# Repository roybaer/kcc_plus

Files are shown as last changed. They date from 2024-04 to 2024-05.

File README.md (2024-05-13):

# KCC plus - a new, enhanced, CPC6128 compatible home computer

**WORK IN PROGRESS**

The _KCC plus_ is a retroactively designed hypothetical early 1990s successor to the KC compact.
The KC compact was a largely compatible clone of the Amstrad CPC 6128, built without custom silicon.

Once completed, it can be considered a cousin of, but not a clone of the Amstrad 6128 Plus.

## Planned feature set

The following hardware features are currently planned

- Between 256 KiB and 1024 KiB of RAM, ideally as a pair of SRAM chips
- Two AY-2-8910 PSGs for additional polyphony and additional control lines, on-board Digiblaster
- 16 bit data path for pixel generation and duplication of the relevant logic for twice the color depth
- Bypassable EGA-like latch in the second RAM chip's data path to keep block fill/copy operations fast
- At least one attribute mode, e.g. for colorful high-res pseudo text modes
- Possibility to optionally double the CPU clock and/or FDC clock, if feasible
- Floppy disk and tape interface
- Internal IDE and Serial ports, if feasible
- The CPC 6128's form factor: System board should fit inside a German CPC 6128 case
- High quality keyboard with n-key rollover
- 50-pin micro ribbon expansion port
- Bi-directional 8-bit printer port (DB25)
- DIN and SCART video output and 3.5 mm audio line-out
- Two digital joystick ports
- Light pen connector
- Laser-cut case, e.g. painted plywood

## Hardware components

These hardware components have been completed

- [Keyboard assembly](kcc_plus_keyboard/README.md) using the CPC 6128 form factor

These hardware components are planned

- Feature evaluation module for CPC
  - Clock generation and audio board
  - RAM and video board
  - Mass storage board
- System board
- Laser-cut case

## License

All design files contained herein may be redistributed and/or modified under the terms of the CERN-OHL-P license.

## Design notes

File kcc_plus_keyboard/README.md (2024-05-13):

# KCC plus - keyboard assembly

This is a mechanical keyboard for the KCC plus.
It uses a CPC 6128 compatible form factor and keyboard matrix.

# Layout

The following layout is recommended for contemporary English.
Suitable off-the-shelf keycap sets are available.

| Switch | Glyph | Switch | Glyph
|:---|:---|:---|:---
| SW1 | Esc | SW39 | F
| SW2 | 1 | SW40 | G
| SW3 | 2 | SW41 | H
| SW4 | 3 | SW42 | J
| SW5 | 4 | SW43 | K
| SW6 | 5 | SW44 | L
| SW7 | 6 | SW45 | ;
| SW8 | 7 | SW46 | '
| SW9 | 8 | SW47 | '
| SW10 | 9 | SW48 | F1
| SW11 | 0 | SW49 | F2
| SW12 | - | SW50 | F3
| SW13 | = | SW51 | shift
| SW14 | backspace | SW52 | Z
| SW15 | F7 | SW53 | X
| SW16 | F8 | SW54 | C
| SW17 | F9 | SW55 | V
| SW18 | tab | SW56 | B
| SW19 | Q | SW57 | N
| SW20 | W | SW58 | M
| SW21 | E | SW59 | ,
| SW22 | R | SW60 | .
| SW23 | T | SW61 | /
| SW24 | Y | SW62 | \
| SW25 | U | SW63 | shift
| SW26 | I | SW64 | F10
| SW27 | O | SW65 | ↑ (up)
| SW28 | P | SW66 | .
| SW29 | [ | SW67 | control
| SW30 | ] | SW68 | option
| SW31 | return | SW69 | command
| SW32 | F4 | SW70 | space
| SW33 | F5 | SW71 | command
| SW34 | F6 | SW72 | del
| SW35 | capslock  | SW73 | enter
| SW36 | A | SW74 | ← (left)
| SW37 | S | SW75 | ↓ (down)
| SW38 | D | SW76 | → (right)

## Pictures

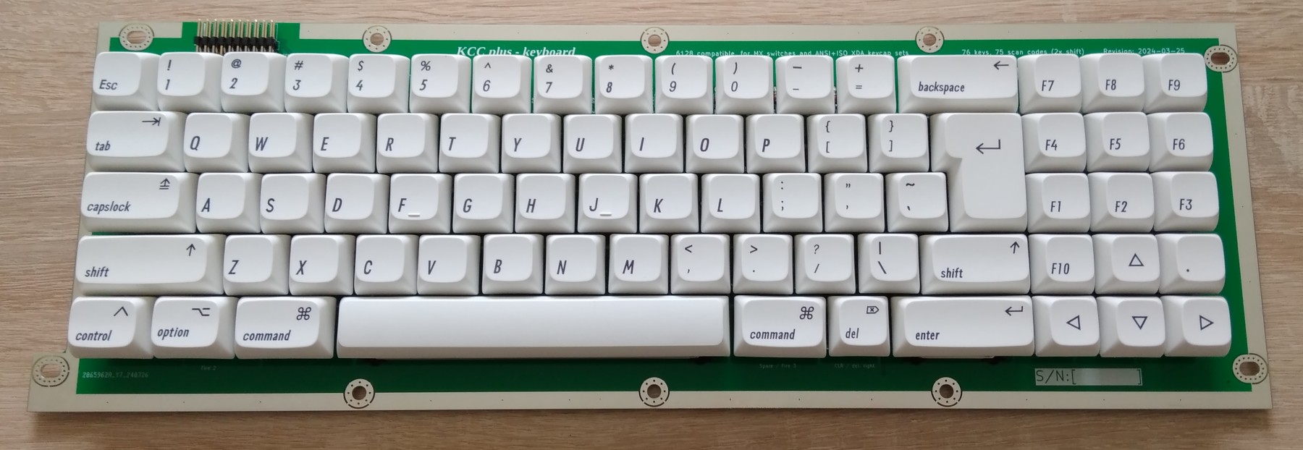
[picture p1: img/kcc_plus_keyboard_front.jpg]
KCC plus - keyboard assembly - front


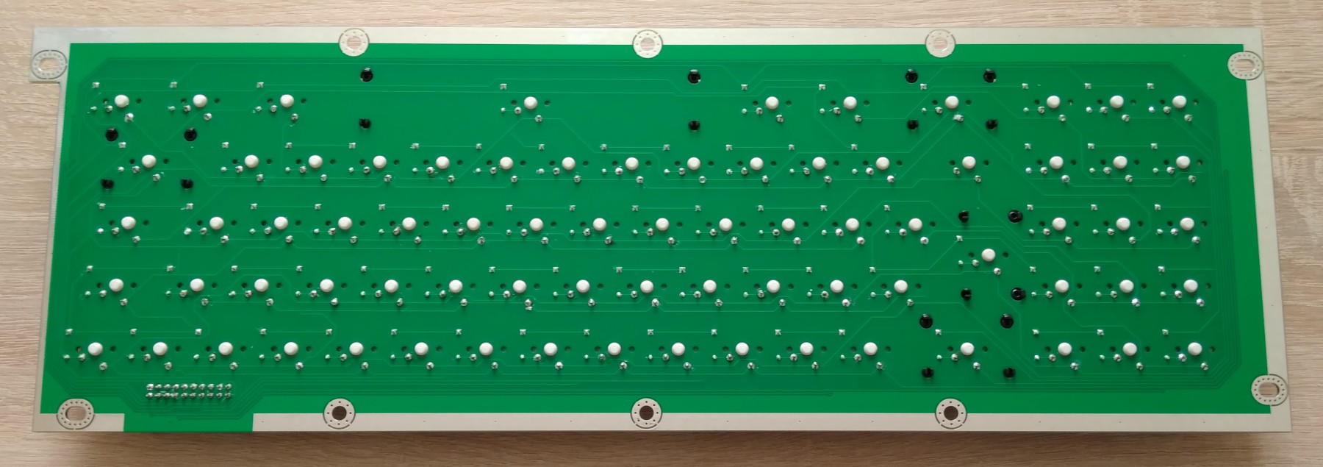
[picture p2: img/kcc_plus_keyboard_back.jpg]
KCC plus - keyboard assembly - back


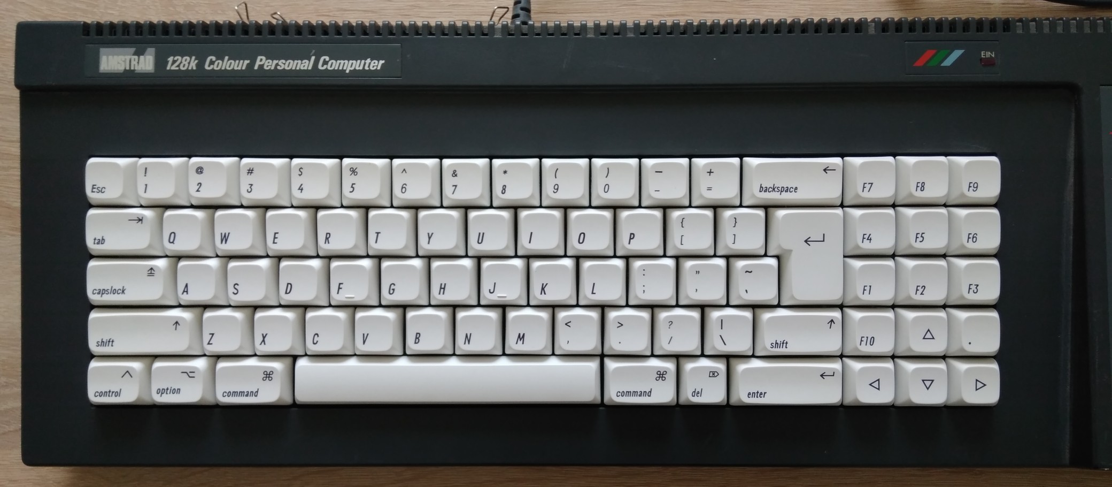
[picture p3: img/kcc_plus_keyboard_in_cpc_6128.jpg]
KCC plus - keyboard assembly - installed in CPC 6128


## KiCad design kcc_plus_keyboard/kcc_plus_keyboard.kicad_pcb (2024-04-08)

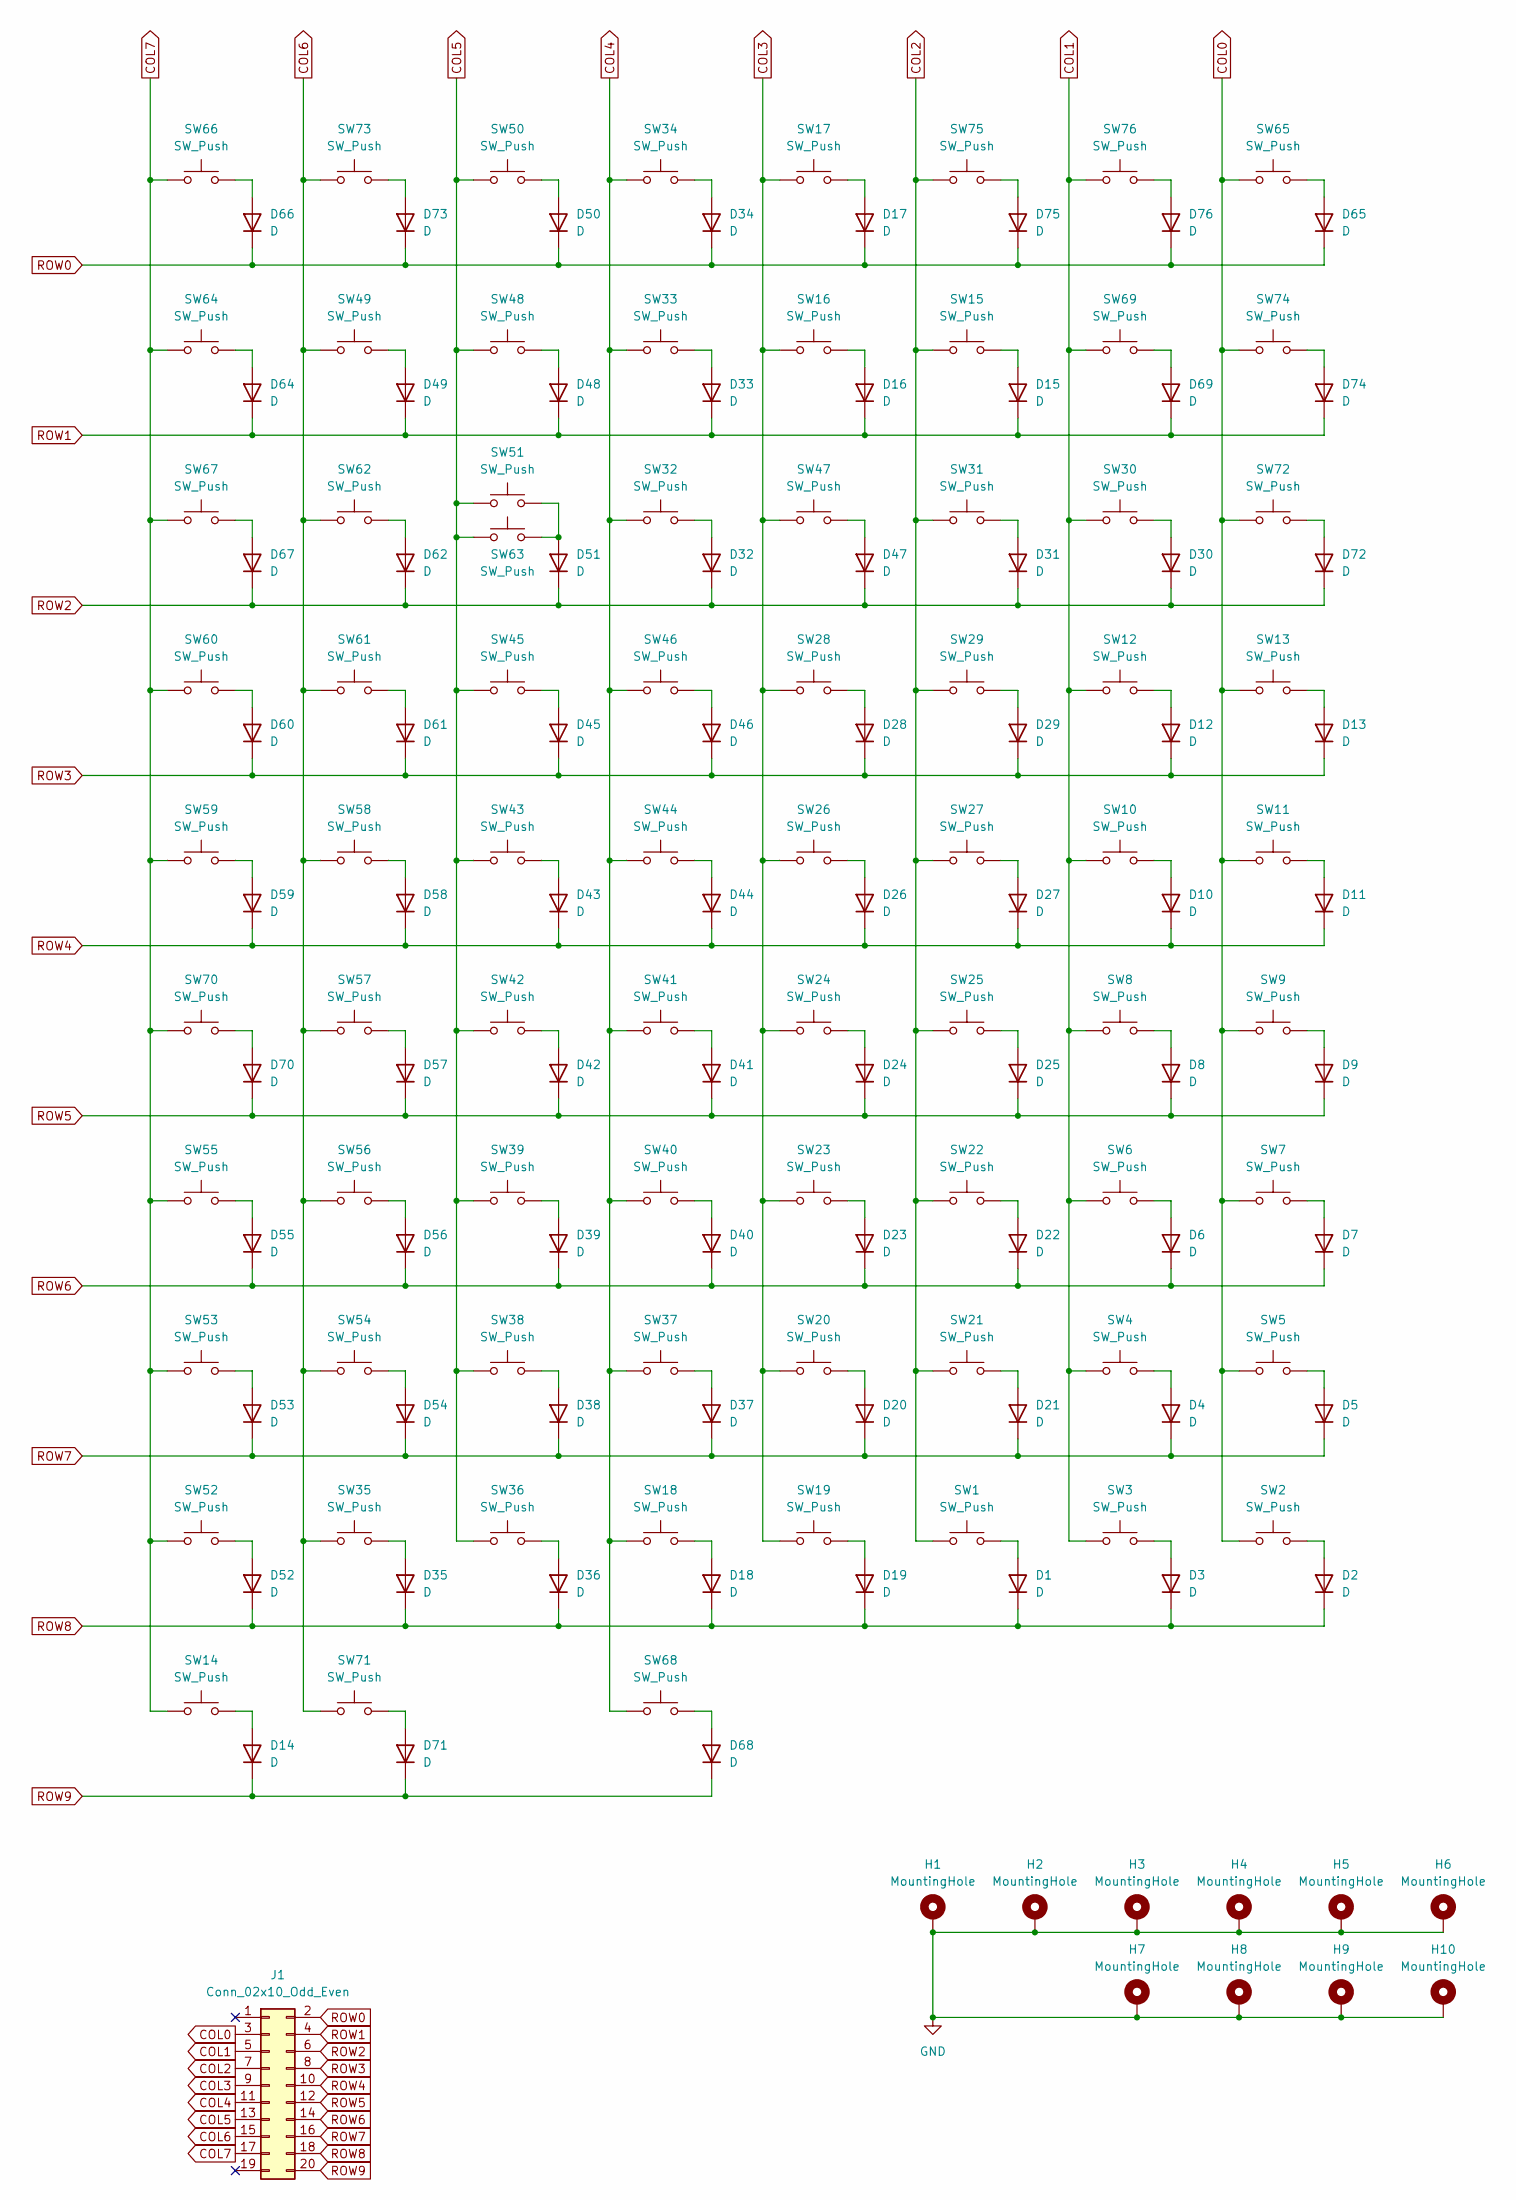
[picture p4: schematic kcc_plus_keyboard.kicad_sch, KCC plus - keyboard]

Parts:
D1, D2, D3, D4, D5, D6, D7, D8, D9, D10, D11, D12, D13, D14, D15, D16, D17, D18, D19, D20, D21, D22, D23, D24, D25, D26, D27, D28, D29, D30, D31, D32, D33, D34, D35, D36, D37, D38, D39, D40, D41, D42, D43, D44, D45, D46, D47, D48, D49, D50, D51, D52, D53, D54, D55, D56, D57, D58, D59, D60, D61, D62, D64, D65, D66, D67, D68, D69, D70, D71, D72, D73, D74, D75, D76: D; D_DO-35_SOD27_P7.62mm_Horizontal
H1, H3, H4, H6: MountingHole; MountingHole_4.3x6.2mm_M4_Pad_Via
H2, H5, H7, H8, H9, H10: MountingHole; MountingHole_4.3mm_M4_Pad_Via
J1: Conn_02x10_Odd_Even; PinHeader_2x10_P2.54mm_Horizontal
SW1, SW2, SW3, SW4, SW5, SW6, SW7, SW8, SW9, SW10, SW11, SW12, SW13, SW15, SW16, SW17, SW19, SW20, SW21, SW22, SW23, SW24, SW25, SW26, SW27, SW28, SW29, SW30, SW32, SW33, SW34, SW36, SW37, SW38, SW39, SW40, SW41, SW42, SW43, SW44, SW45, SW46, SW47, SW48, SW49, SW50, SW52, SW53, SW54, SW55, SW56, SW57, SW58, SW59, SW60, SW61, SW62, SW64, SW65, SW66, SW72, SW74, SW75, SW76: SW_Push; SW_Cherry_MX_1.00u_PCB
SW14: SW_Push; SW_Cherry_MX_2.00u_PCB
SW18, SW69, SW71: SW_Push; SW_Cherry_MX_1.50u_PCB
SW31: SW_Push; SW_Cherry_MX_ISOEnter_PCB
SW35, SW63: SW_Push; SW_Cherry_MX_1.75u_PCB
SW51, SW73: SW_Push; SW_Cherry_MX_2.25u_PCB
SW67, SW68: SW_Push; SW_Cherry_MX_1.25u_PCB
SW70: SW_Push; SW_Cherry_MX_6.25u_PCB

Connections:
COL0: J1.3, SW2.1, SW5.1, SW7.1, SW9.1, SW11.1, SW13.1, SW65.1, SW72.1, SW74.1
COL1: J1.5, SW3.1, SW4.1, SW6.1, SW8.1, SW10.1, SW12.1, SW30.1, SW69.1, SW76.1
COL2: J1.7, SW1.1, SW15.1, SW21.1, SW22.1, SW25.1, SW27.1, SW29.1, SW31.1, SW75.1
COL3: J1.9, SW16.1, SW17.1, SW19.1, SW20.1, SW23.1, SW24.1, SW26.1, SW28.1, SW47.1
COL4: J1.11, SW18.1, SW32.1, SW33.1, SW34.1, SW37.1, SW40.1, SW41.1, SW44.1, SW46.1, SW68.1
COL5: J1.13, SW36.1, SW38.1, SW39.1, SW42.1, SW43.1, SW45.1, SW48.1, SW50.1, SW51.1, SW63.1
COL6: J1.15, SW35.1, SW49.1, SW54.1, SW56.1, SW57.1, SW58.1, SW61.1, SW62.1, SW71.1, SW73.1
COL7: J1.17, SW14.1, SW52.1, SW53.1, SW55.1, SW59.1, SW60.1, SW64.1, SW66.1, SW67.1, SW70.1
GND: H1.1, H2.1, H3.1, H4.1, H5.1, H6.1, H7.1, H8.1, H9.1, H10.1
unnamed: D1.2 (A), SW1.2
unnamed: D2.2 (A), SW2.2
unnamed: D3.2 (A), SW3.2
unnamed: D4.2 (A), SW4.2
unnamed: D5.2 (A), SW5.2
unnamed: D6.2 (A), SW6.2
unnamed: D7.2 (A), SW7.2
unnamed: D8.2 (A), SW8.2
unnamed: D9.2 (A), SW9.2
unnamed: D10.2 (A), SW10.2
unnamed: D11.2 (A), SW11.2
unnamed: D12.2 (A), SW12.2
unnamed: D13.2 (A), SW13.2
unnamed: D14.2 (A), SW14.2
unnamed: D15.2 (A), SW15.2
unnamed: D16.2 (A), SW16.2
unnamed: D17.2 (A), SW17.2
unnamed: D18.2 (A), SW18.2
unnamed: D19.2 (A), SW19.2
unnamed: D20.2 (A), SW20.2
unnamed: D21.2 (A), SW21.2
unnamed: D22.2 (A), SW22.2
unnamed: D23.2 (A), SW23.2
unnamed: D24.2 (A), SW24.2
unnamed: D25.2 (A), SW25.2
unnamed: D26.2 (A), SW26.2
unnamed: D27.2 (A), SW27.2
unnamed: D28.2 (A), SW28.2
unnamed: D29.2 (A), SW29.2
unnamed: D30.2 (A), SW30.2
unnamed: D31.2 (A), SW31.2
unnamed: D32.2 (A), SW32.2
unnamed: D33.2 (A), SW33.2
unnamed: D34.2 (A), SW34.2
unnamed: D35.2 (A), SW35.2
unnamed: D36.2 (A), SW36.2
unnamed: D37.2 (A), SW37.2
unnamed: D38.2 (A), SW38.2
unnamed: D39.2 (A), SW39.2
unnamed: D40.2 (A), SW40.2
unnamed: D41.2 (A), SW41.2
unnamed: D42.2 (A), SW42.2
unnamed: D43.2 (A), SW43.2
unnamed: D44.2 (A), SW44.2
unnamed: D45.2 (A), SW45.2
unnamed: D46.2 (A), SW46.2
unnamed: D47.2 (A), SW47.2
unnamed: D48.2 (A), SW48.2
unnamed: D49.2 (A), SW49.2
unnamed: D50.2 (A), SW50.2
unnamed: D51.2 (A), SW51.2, SW63.2
unnamed: D52.2 (A), SW52.2
unnamed: D53.2 (A), SW53.2
unnamed: D54.2 (A), SW54.2
unnamed: D55.2 (A), SW55.2
unnamed: D56.2 (A), SW56.2
unnamed: D57.2 (A), SW57.2
unnamed: D58.2 (A), SW58.2
unnamed: D59.2 (A), SW59.2
unnamed: D60.2 (A), SW60.2
unnamed: D61.2 (A), SW61.2
unnamed: D62.2 (A), SW62.2
unnamed: D64.2 (A), SW64.2
unnamed: D65.2 (A), SW65.2
unnamed: D66.2 (A), SW66.2
unnamed: D67.2 (A), SW67.2
unnamed: D68.2 (A), SW68.2
unnamed: D69.2 (A), SW69.2
unnamed: D70.2 (A), SW70.2
unnamed: D71.2 (A), SW71.2
unnamed: D72.2 (A), SW72.2
unnamed: D73.2 (A), SW73.2
unnamed: D74.2 (A), SW74.2
unnamed: D75.2 (A), SW75.2
unnamed: D76.2 (A), SW76.2
ROW0: D17.1 (K), D34.1 (K), D50.1 (K), D65.1 (K), D66.1 (K), D73.1 (K), D75.1 (K), D76.1 (K), J1.2
ROW1: D15.1 (K), D16.1 (K), D33.1 (K), D48.1 (K), D49.1 (K), D64.1 (K), D69.1 (K), D74.1 (K), J1.4
ROW2: D30.1 (K), D31.1 (K), D32.1 (K), D47.1 (K), D51.1 (K), D62.1 (K), D67.1 (K), D72.1 (K), J1.6
ROW3: D12.1 (K), D13.1 (K), D28.1 (K), D29.1 (K), D45.1 (K), D46.1 (K), D60.1 (K), D61.1 (K), J1.8
ROW4: D10.1 (K), D11.1 (K), D26.1 (K), D27.1 (K), D43.1 (K), D44.1 (K), D58.1 (K), D59.1 (K), J1.10
ROW5: D8.1 (K), D9.1 (K), D24.1 (K), D25.1 (K), D41.1 (K), D42.1 (K), D57.1 (K), D70.1 (K), J1.12
ROW6: D6.1 (K), D7.1 (K), D22.1 (K), D23.1 (K), D39.1 (K), D40.1 (K), D55.1 (K), D56.1 (K), J1.14
ROW7: D4.1 (K), D5.1 (K), D20.1 (K), D21.1 (K), D37.1 (K), D38.1 (K), D53.1 (K), D54.1 (K), J1.16
ROW8: D1.1 (K), D2.1 (K), D3.1 (K), D18.1 (K), D19.1 (K), D35.1 (K), D36.1 (K), D52.1 (K), J1.18
ROW9: D14.1 (K), D68.1 (K), D71.1 (K), J1.20

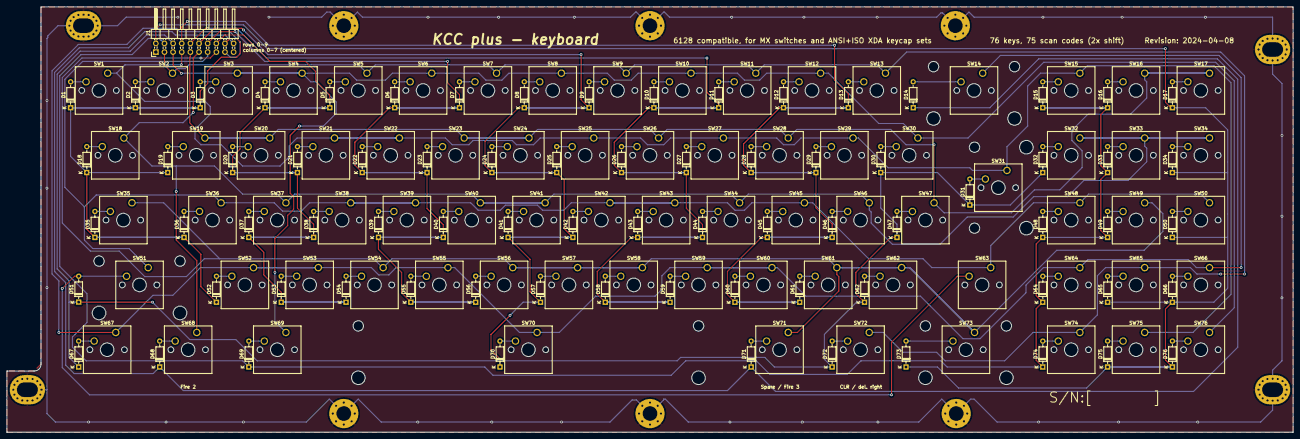
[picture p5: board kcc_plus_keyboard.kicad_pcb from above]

Board: 2 copper layers, 378.0 x 125.0 mm, 162 parts (0 on the bottom side), 94 nets.

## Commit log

2024-04-08 initial board version
    [kcc_plus_keyboard.kicad_pcb, kcc_plus_keyboard.kicad_sch]
2024-04-08 move three diodes away from stabilizers
    [kcc_plus_keyboard.kicad_pcb]
